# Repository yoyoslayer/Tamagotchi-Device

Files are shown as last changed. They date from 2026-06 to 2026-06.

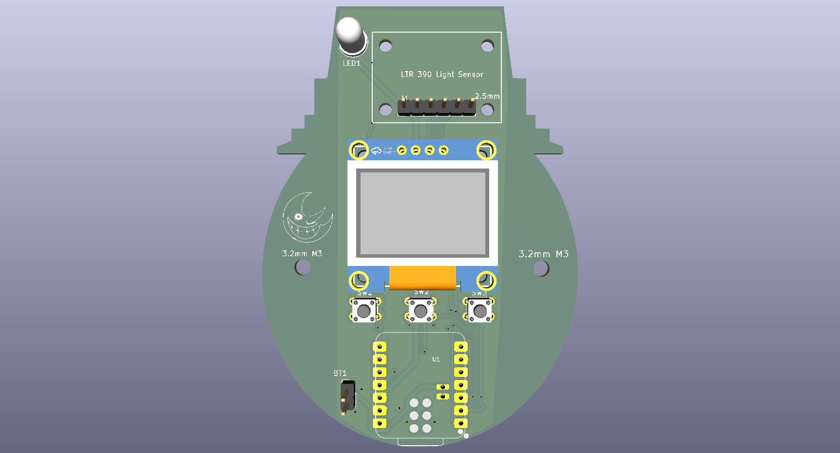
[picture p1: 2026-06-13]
Images/3D File Export Front.png

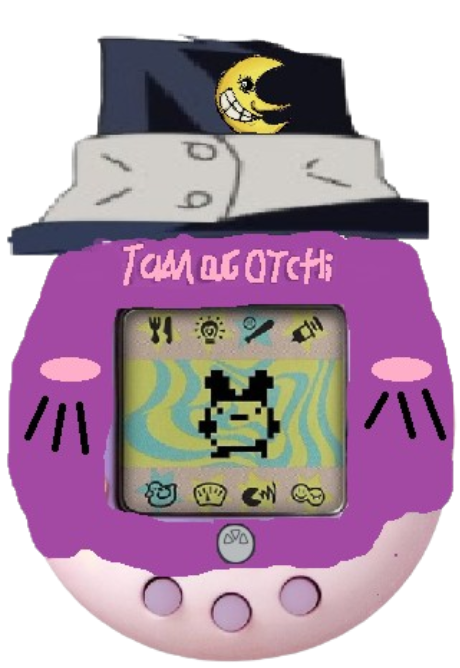
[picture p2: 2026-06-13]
Images/Rough Draft Case.png

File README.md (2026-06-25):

# Photophage. A pet that feeds on light

## What it is
I made a special digitel pet that you can carry around with you. It is like the Tamagotchi toys from the 90s but I built it myself and custom made. The pet is on a screen that comes with pressable buttons a buzzer, a LED, and a sensor that can tell if it is in the light or dark. All of this is inside an egg-shaped case that I made using a 3D printer. The case also takes inspiration and certain design elements from the AniManga, Soul Eater.
What makes my tamagotchi unique is that it can tell what is going on in your environment. It has a sensor that can tell if it present in sunlight, indoor lighting or if it is dark so it will react to where it is and not just to what you do with the buttons.

## What it does / how to use it
- There are three buttons that you can use to take care of the pet: Feed, Play, Sleep.
- The pet has three things that you need to keep track of: Hunger, Happiness, Energy. These will go down over time so you need to check on the pet
If you press Feed, the pets Hunger will go up.
If you press Play, the pets Happiness will go up. Its Energy will go down a little bit.
If you press Sleep the pets Energy will go up.

- The pets face will change depending on how it's feeling. It will be happy if it is doing well okay if it is getting by and sad if something is wrong.
- There is a light that will change color depending on how the pet is feeling: green means it is happy amber means it is okay and red means it needs help.
- When you press a button the pet will make a beep.
- The pet can tell if it is in sunlight or indoor light and it will show you this every minutes. If it is dark it will not say anything.
- The pet runs on a battery that you can recharge and it lives in a custom egg-shaped case that I made.

## Assembly
1. Download CAD files from onshape and the gerber zip.
2. Purchase the parts from the BOM or select alternatives. (Screws must be exact identicals in dimensions)
3. Order the PCB from JLCPCB (or your prefferred vendor) using the gerber file attached
4. Print the case enclosure that houses the PCB and components
5. Cut velcro tape to reasonable sizes and attach one half to the Battery enclosure in the bottom case and the other half to the battery.
6. Attach, assemble, and solder the parts to the PCB as it looks according to the Onshape CAD
   - Be sure to check your battery connection after soldering
   - Solder the battery cell into the bottom side of the PCB rather than the top
   - The JST PH connector's wire will need to be shortened significantly to fit in the bottom case or wrapped neatly. Solder the connector into the battery cell.
7. Insert heat inserts into their respective mounting holes, place PCB, then screw in the screws
8. Repeat step 6 for the case
9. Assembly complete. YAYYY

## Why I made it
I made Photophage because I wanted to try something challenging. This was my 1st time building a whole project from scratch and I wanted to add some special features like the light sensor and the mood light. I chose to make it a virtual pet that feeds on light because I think it is a fun and interesting idea. I used this project to learn about all the parts of building an electronics project from designing the circuit board to writing the code and making the case. This serves as my first submission to the program Fallout, created by HackClub, an organization that promotes and encourages teens to become engineers/programmers.


Tamagotchi Device 3D File Export Front
Tamagotchi Device 3D File Export Back


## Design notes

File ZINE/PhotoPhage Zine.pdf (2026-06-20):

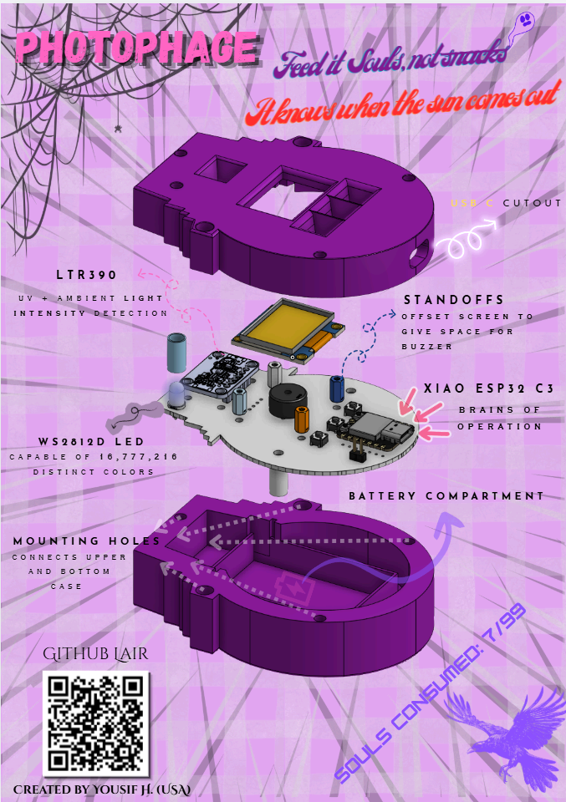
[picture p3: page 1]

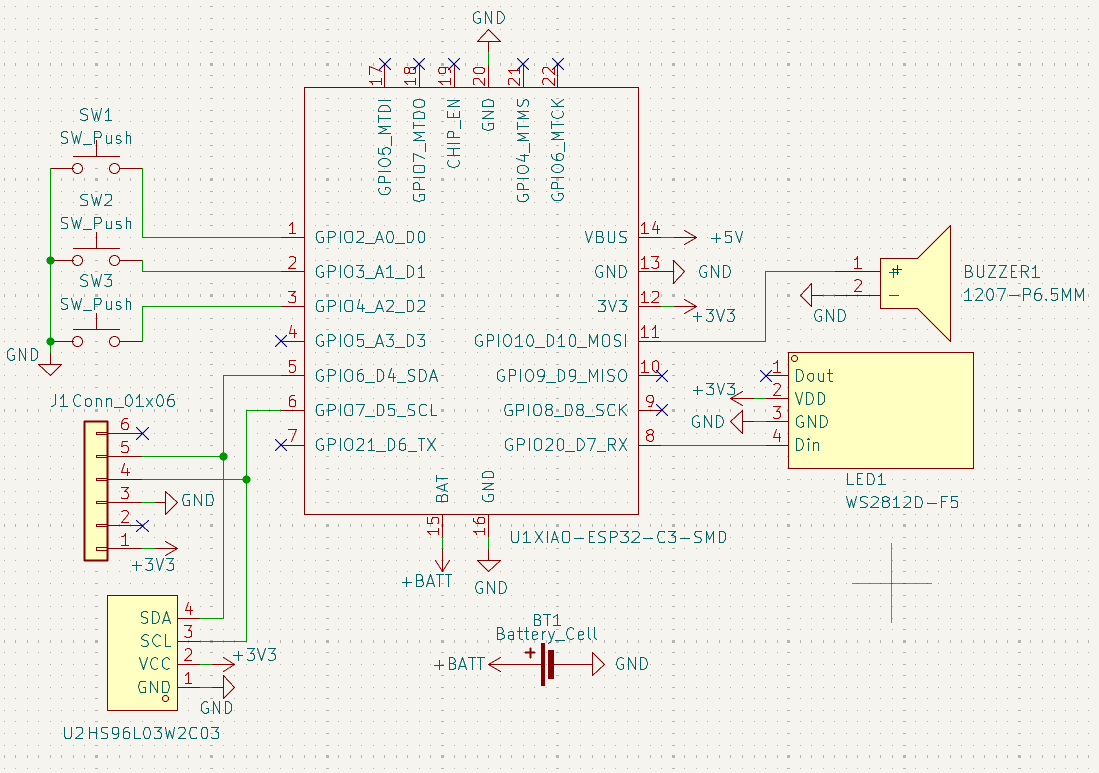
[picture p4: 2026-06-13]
Images/Schematic Image.png

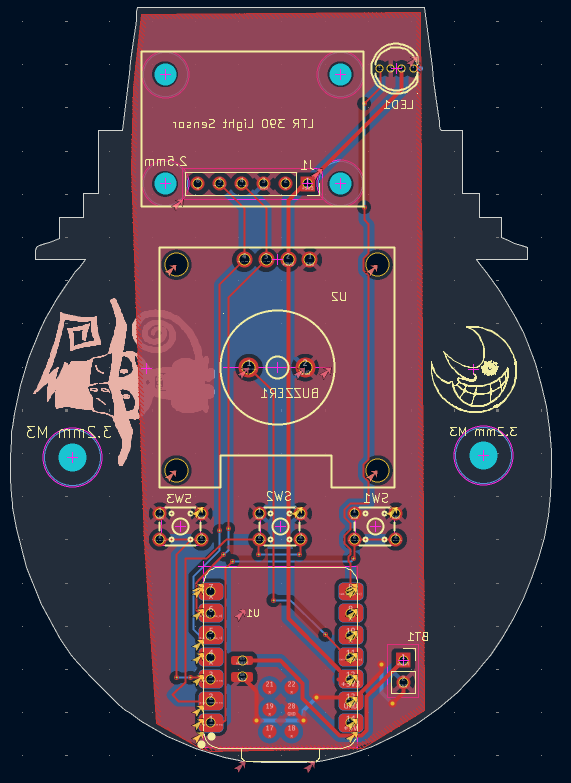
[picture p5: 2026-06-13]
Images/PCB View Bottom.png

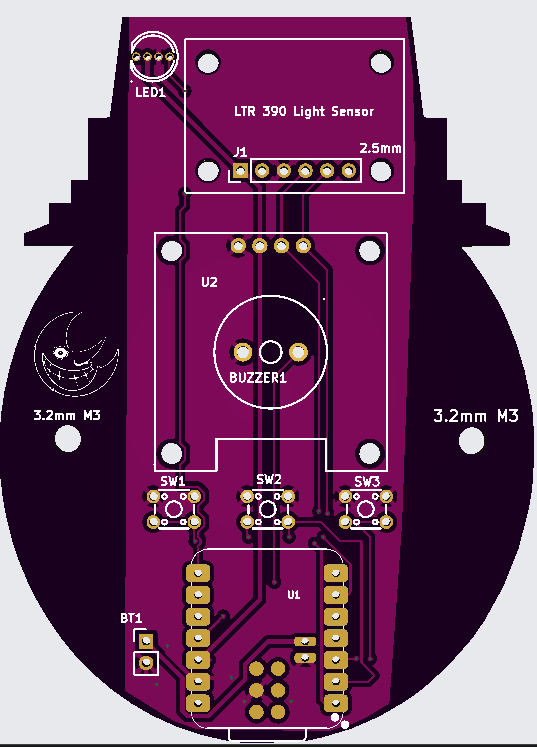
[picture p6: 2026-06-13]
Images/JLCPCB View PCB.png

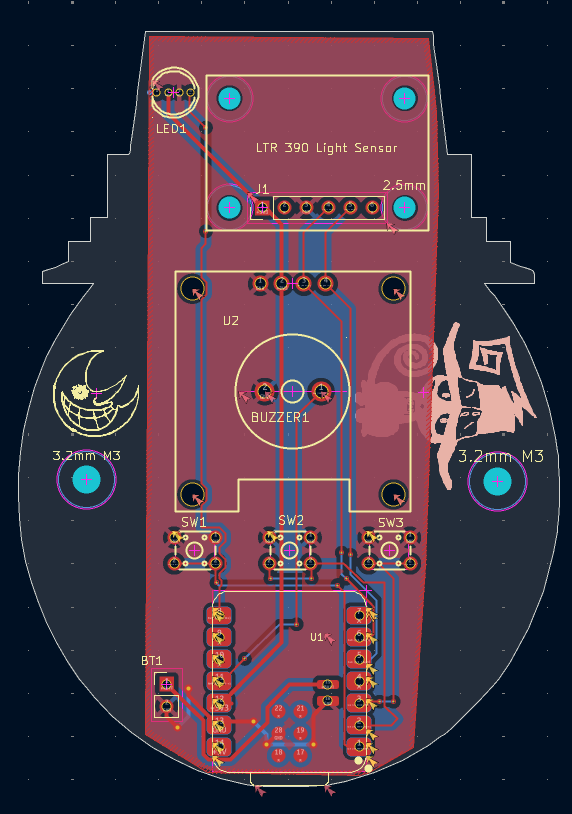
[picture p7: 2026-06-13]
Images/PCB View Top.png

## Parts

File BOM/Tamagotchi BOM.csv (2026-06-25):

Item | Description | Quantity | Individual piece quantity | Unit Price ($) | Total Price ($) | URL | Running Total ($ with Tax)
XIAO ESP32C3 | Microcontroller Unit | 1 | 1 | $4.99 | $4.99 | https://www.digikey.com/en/products/detail/seeed-technology-co-ltd/113991054/16652880 | $13.48
BRKWY 0.1" 36POS MALE 10PK | Breakaway Header Male Pin 2.54mm for Battery Cell | 1 | 10 | $4.95 | $4.95 | https://www.digikey.com/en/products/detail/adafruit-industries-llc/392/21283800 | $18.75
Worldsemi WS2812D-F5 | Multi Color LED | 1 | 5 | 0.2512 | $1.26 | https://www.lcsc.com/product-detail/C190565.html | 30
HS HS96L03W2C03 | OLED Screen | 1 | 1 | 2.244 | 2.244 | https://www.lcsc.com/product-detail/C5248080.html | 32.34
BZCN TSC016A04518A | Pressable Buttons | 1 | 50 | $0.01 | $0.54 | https://www.lcsc.com/product-detail/C2888493.html | 33.35
XHXDZ 1207-P6.5MM | Buzzer | 1 | 10 | $0.06 | $0.57 | https://www.lcsc.com/product-detail/C49246964.html | 34.07
Adafruit LTR390 | UV and Light Sensor | 1 | 1 | $4.95 | $4.95 | https://www.adafruit.com/product/4831 | 45.81
BATTERY LITH-ION 3.7V 1.2AH | Battery for powering Device | 1 | 1 | $3.00 | $3.00 | https://ydlbattery.com/products/100pcs-3-7v-1200mah-603450-lithium-polymer-battery | 63.54
20 SETS Mini Micro JST 2.0 PH 2-Pin Connector plug with Wires Cables 100MM | Connectors to wire the battery into the battery header pins | 1 | 20 | 2.68 | 2.68 | https://www.aliexpress.us/item/2251832479273592.html | 64.6
M3(OD4mm) 50Pcs Length 4mm | Heat Inserts to screw the nails into | 1 | 50 | $3.28 | $3.28 | https://www.aliexpress.us/item/3256810175696879.html | 67.7
M4(OD6mm) 30Pcs Length 4mm | Heat Inserts to screw the nails into | 1 | 30 | $3.37 | $3.37 | https://www.aliexpress.us/item/3256810175696879.html | 70.9
TPU 3D Printer Flexible Filament 250g (0.55lbs) 1.75mm Length 80M, Black, white | 3D Printer Filament | 1 | 1 | $21.78 | $21.78 | https://www.aliexpress.us/item/3256811629074080.html | 78.91
Self Adhesive Tape Hook and Loop Strips | Velcro to attach Battery to case | 1 | 5 | $3.28 | $3.28 | https://www.aliexpress.us/item/3256809228271173.html | 80.55
PCB from JLCPCB | The PCB that will be used for this project | 1 | 5 | $2.50 | $2.50 | https://jlcpcb.com/ | 85.85
Hakko CHP-170 | Micro Soft Wire Cutter | 1 | 1 | $5.20 | $5.20 | https://www.tequipment.net/Hakko/CHP-170/Cutting-Tools/ | 106.86
M4 x 0.7mm Zinc-Plated Socket Head Screw (5mm Length) | M4 Screws | 1 | 25 | $2.89 | $2.89 | https://www.gobilda.com/2800-series-zinc-plated-steel-socket-head-screw-m4-x-0-7mm-5mm-length-25-pack/ | 116.36
Zinc-Plated Steel Socket Head Screw (M3 x 0.5mm, 6mm Length) | M3 Screws | 1 | 6 | $2.99 | $2.99 | https://www.gobilda.com/zinc-plated-steel-socket-head-screw-m3-x-0-5mm-6mm-length-6-pack/ | 119.55
Note: Welcome Deal is applied to running total for Aliexpress items, my price will differ from yours if you do not have a welcome deal. There is no way to view my price without the welcome deal at checkout so keep that in mind

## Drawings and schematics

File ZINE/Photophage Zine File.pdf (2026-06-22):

# PPPhhhoootttoooppphhhaaagggeee

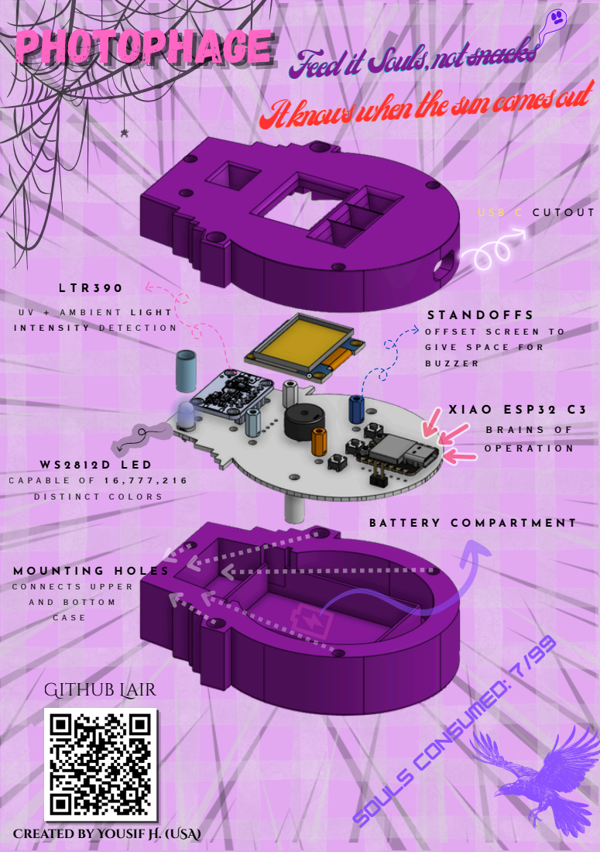
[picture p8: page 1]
Github Lair; Souls consumed: 7/99

Feedit Souls,notsnacks

Itknowswhenthesuncomesout Itknowswhenthesuncomesout Itknowswhenthesuncomesout

Created by Yousif H. (USA)

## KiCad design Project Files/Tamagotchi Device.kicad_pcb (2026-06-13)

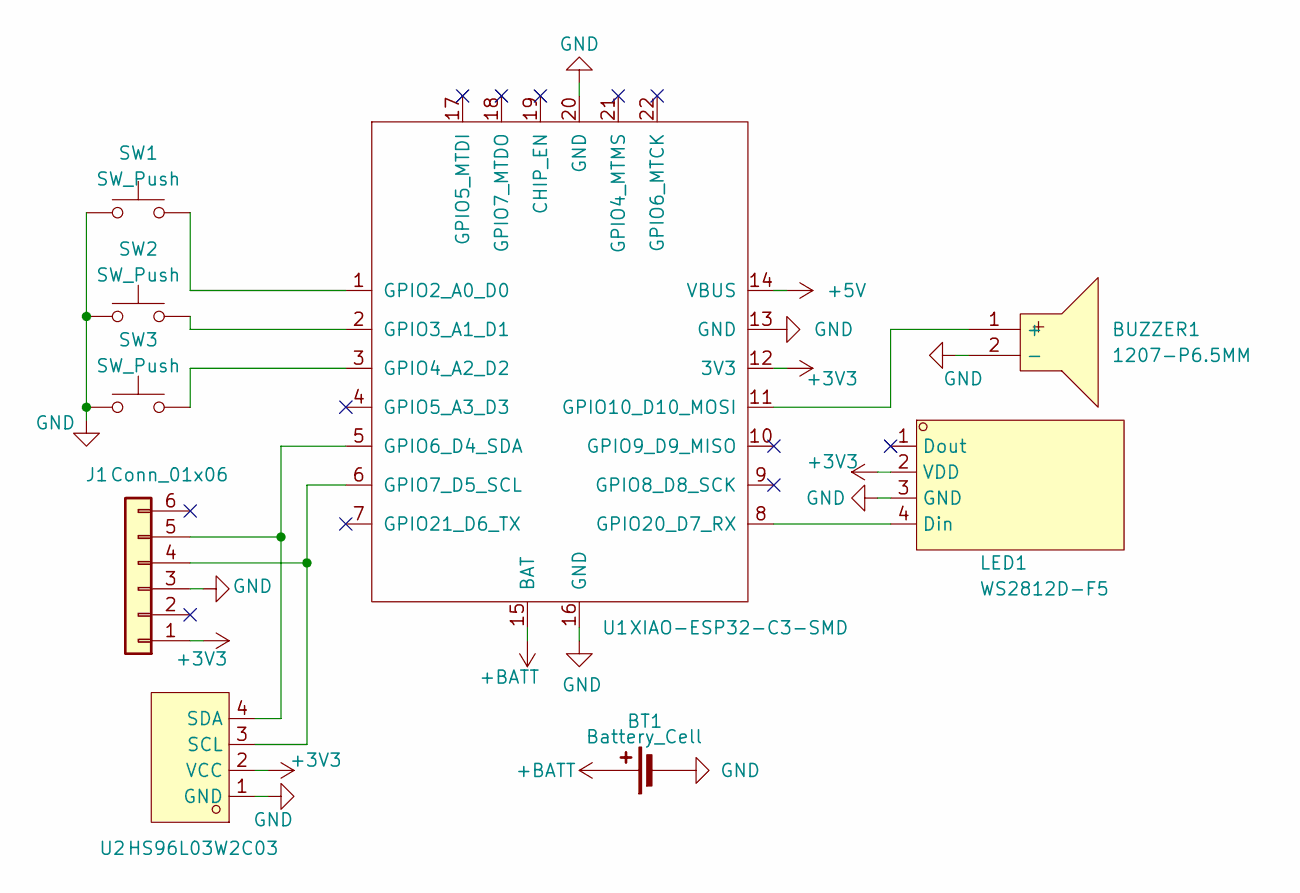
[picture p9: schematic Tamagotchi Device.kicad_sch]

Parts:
BT1: Battery_Cell; PinHeader_1x02_P2.54mm_Vertical
BUZZER1: 1207-P6.5MM; BUZ-TH_BD12.5-P6.50-D1.4; MPN 1207-P6.5MM; LCSC Part C49246964
J1: Conn_01x06; PinHeader_1x06_P2.54mm_Vertical
LED1: WS2812D-F5; LED-TH_4P-BD5.8-P1.30; MPN WS2812D-F5; LCSC Part C190565
SW1, SW2, SW3: SW_Push; SW-TH_4P-L4.5-W4.5-P3.00-LS4.8
U1: XIAO-ESP32-C3-SMD
U2: HS96L03W2C03; OLED-TH_L27.8-W27.2-P2.54_C9900033791; MPN HS96L03W2C03; LCSC Part C5248080

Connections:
+3V3: J1.1, LED1.2 (VDD), U1.12 (3V3), U2.2 (VCC)
+5V: U1.14 (VBUS)
+BATT: BT1.1 (+), U1.15 (BAT)
GND: BT1.2 (-), BUZZER1.2 (-), J1.3, LED1.3 (GND), SW1.1, SW2.1, SW3.1, U1.13 (GND), U1.16 (GND), U1.20 (GND), U2.1 (GND)
unnamed: BUZZER1.1 (+), U1.11 (GPIO10_D10_MOSI)
unnamed: J1.4, U1.6 (GPIO7_D5_SCL), U2.3 (SCL)
unnamed: J1.5, U1.5 (GPIO6_D4_SDA), U2.4 (SDA)
unnamed: LED1.4 (Din), U1.8 (GPIO20_D7_RX)
unnamed: SW1.2, U1.1 (GPIO2_A0_D0)
unnamed: SW2.2, U1.2 (GPIO3_A1_D1)
unnamed: SW3.2, U1.3 (GPIO4_A2_D2)

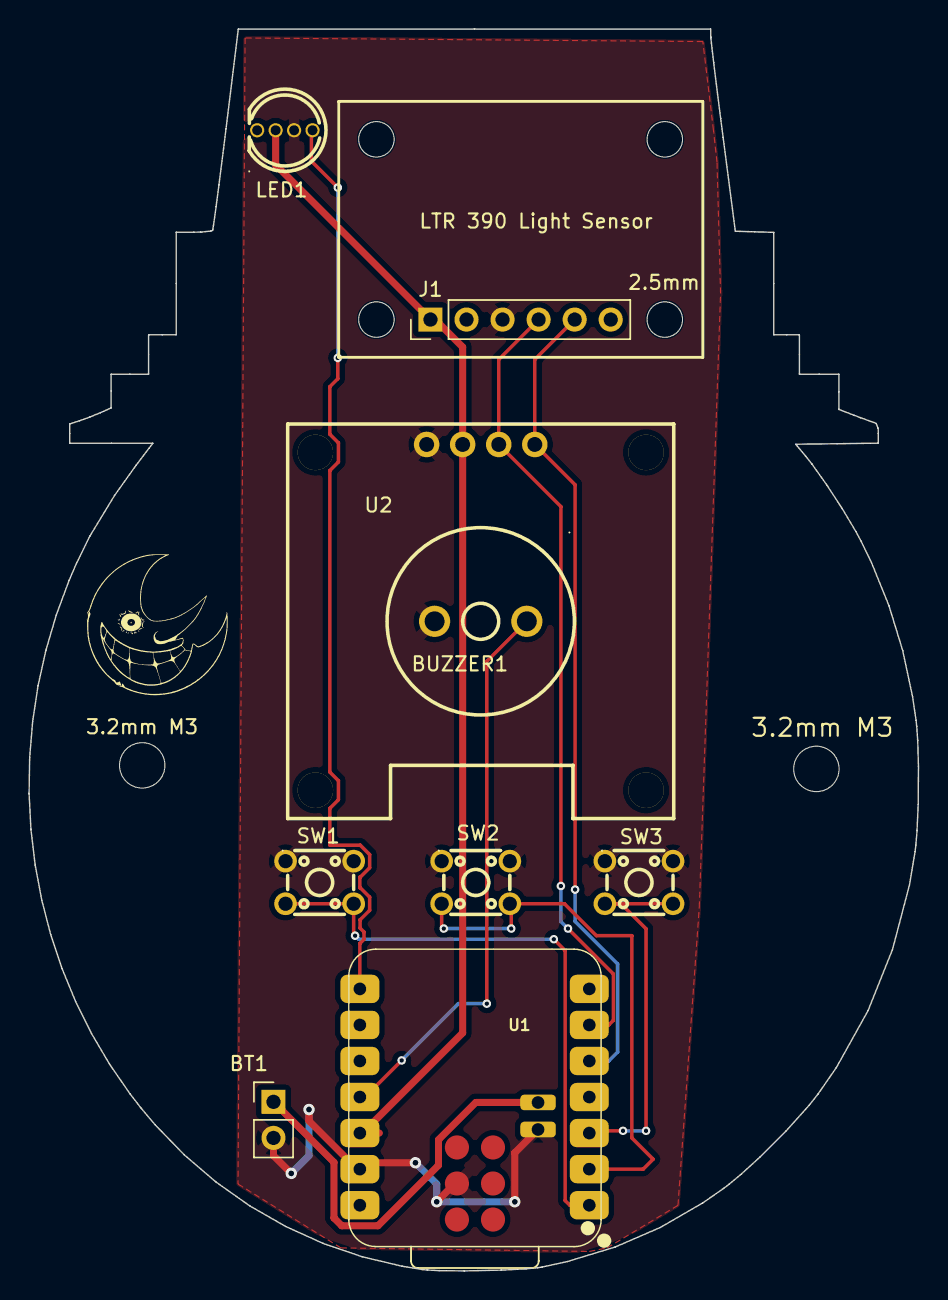
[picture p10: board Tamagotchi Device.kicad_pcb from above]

Board: 2 copper layers, 62.7 x 87.5 mm, 12 parts (0 on the bottom side), 10 nets.

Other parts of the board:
2.5mm, 2.5mm#2: MountingHole_2.5mm
3.2mm M3: MountingHole_3.2mm_M3

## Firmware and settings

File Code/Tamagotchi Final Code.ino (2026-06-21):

#include <Wire.h>
#include <Adafruit_GFX.h>
#include <Adafruit_SSD1306.h>
#include <Adafruit_NeoPixel.h>
#include <Adafruit_LTR390.h>

#define Screen_WIDTH 128
#define Screen_HEIGHT 64
#define OLED_RESET -1
Adafruit_SSD1306 display(Screen_WIDTH, Screen_HEIGHT, &Wire, OLED_RESET);

Adafruit_LTR390 ltr = Adafruit_LTR390();

#define BTN_LEFT   2
#define BTN_CENTER 3
#define BTN_RIGHT  4

#define SDA_PIN 6
#define SCL_PIN 7

#define BUZZER_PIN 10

#define LED_PIN 20

Adafruit_NeoPixel pixel(1, LED_PIN, NEO_GRB + NEO_KHZ800);

#define ALS_DARK_LEVEL 30
#define UV_SUN_LEVEL   50

#define ANNOUNCE_INTERVAL 300000UL
#define ANNOUNCE_DURATION 3000UL

struct Pet {
  int hunger;
  int happiness;
  int energy;
  unsigned long age;
};

Pet pet;

enum Screen {
  SCREEN_MAIN,
  SCREEN_FEED,
  SCREEN_PLAY,
  SCREEN_SLEEP,
};

Screen currentScreen = SCREEN_MAIN;

enum LightType {
  LIGHT_DARK,
  LIGHT_INDOOR,
  LIGHT_SUN,
};

LightType lightType = LIGHT_DARK;

void setup() {
  Serial.begin(115200);

  pinMode(BTN_LEFT, INPUT_PULLUP);
  pinMode(BTN_CENTER, INPUT_PULLUP);
  pinMode(BTN_RIGHT, INPUT_PULLUP);
  pinMode(BUZZER_PIN, OUTPUT);

  Wire.begin(SDA_PIN, SCL_PIN);

  display.begin(SSD1306_SWITCHCAPVCC, 0x3C);
  display.clearDisplay();
  display.setTextSize(1);
  display.setTextColor(SSD1306_WHITE);
  display.setCursor(0, 0);
  display.println("Tamagotchi Init...");
  display.display();

  if (!ltr.begin()) {
    Serial.println("LTR390 not found - check wiring/address");
  }
  ltr.setGain(LTR390_GAIN_3);
  ltr.setResolution(LTR390_RESOLUTION_16BIT);

  pixel.begin();
  pixel.setBrightness(50);
  pixel.clear();
  pixel.show();

  delay(1000);

  pet.hunger = 80;
  pet.happiness = 80;
  pet.energy = 80;
  pet.age = 0;
}

unsigned long lastUpdate = 0;

void updatePet() {
  if (millis() - lastUpdate > 5000) {
    pet.hunger--;
    pet.happiness--;
    pet.energy--;

    if (pet.hunger < 0) pet.hunger = 0;
    if (pet.happiness < 0) pet.happiness = 0;
    if (pet.energy < 0) pet.energy = 0;

    pet.age += 5;
    lastUpdate = millis();
  }
}

unsigned long lastButtonPress = 0;

void checkButtons() {
  if (millis() - lastButtonPress < 200) return;

  if (digitalRead(BTN_LEFT) == LOW) {
    currentScreen = SCREEN_FEED;
    tone(BUZZER_PIN, 1000, 50);
    lastButtonPress = millis();
  }
  else if (digitalRead(BTN_CENTER) == LOW) {
    currentScreen = SCREEN_PLAY;
    tone(BUZZER_PIN, 1000, 50);
    lastButtonPress = millis();
  }
  else if (digitalRead(BTN_RIGHT) == LOW) {
    currentScreen = SCREEN_SLEEP;
    tone(BUZZER_PIN, 1000, 50);
    lastButtonPress = millis();
  }
}

void handleScreenLogic() {
  switch (currentScreen) {
    case SCREEN_FEED:
      pet.hunger += 10;
      if (pet.hunger > 100) pet.hunger = 100;
      currentScreen = SCREEN_MAIN;
      break;

    case SCREEN_PLAY:
      pet.happiness += 10;
      pet.energy -= 5;
      if (pet.happiness > 100) pet.happiness = 100;
      if (pet.energy < 0) pet.energy = 0;
      currentScreen = SCREEN_MAIN;
      break;

    case SCREEN_SLEEP:
      pet.energy += 15;
      if (pet.energy > 100) pet.energy = 100;
      currentScreen = SCREEN_MAIN;
      break;

    case SCREEN_MAIN:
      break;
  }
}

unsigned long lastLightCheck = 0;

void checkLight() {
  if (millis() - lastLightCheck < 2000) return;
  lastLightCheck = millis();

  ltr.setMode(LTR390_MODE_ALS);
  delay(50);
  uint32_t visible = ltr.readALS();

  ltr.setMode(LTR390_MODE_UVS);
  delay(50);
  uint32_t uv = ltr.readUVS();

  if (visible < ALS_DARK_LEVEL) {
    lightType = LIGHT_DARK;
  } else if (uv > UV_SUN_LEVEL) {
    lightType = LIGHT_SUN;
  } else {
    lightType = LIGHT_INDOOR;
  }

  Serial.print("visible(ALS)="); Serial.print(visible);
  Serial.print("  uv(UVS)=");    Serial.print(uv);
  Serial.print("  -> ");
  Serial.println(lightType == LIGHT_SUN ? "SUN"
               : lightType == LIGHT_INDOOR ? "INDOOR" : "DARK");
}

unsigned long lastAnnounce = 0;
unsigned long announceUntil = 0;

void updateAnnounce() {
  if (millis() - lastAnnounce > ANNOUNCE_INTERVAL && lightType != LIGHT_DARK) {
    lastAnnounce = millis();
    announceUntil = millis() + ANNOUNCE_DURATION;
  }
}

bool isAnnouncing() {
  return millis() < announceUntil;
}

int petMood() {
  if (pet.hunger < 30 || pet.happiness < 30 || pet.energy < 30) return 0;
  if (pet.hunger > 50 && pet.happiness > 50 && pet.energy > 50) return 2;
  return 1;
}

void updateLED() {
  uint32_t color;
  switch (petMood()) {
    case 0:  color = pixel.Color(255, 0, 0);   break;
    case 2:  color = pixel.Color(0, 255, 0);   break;
    default: color = pixel.Color(255, 170, 0);
  }
  pixel.setPixelColor(0, color);
  pixel.show();
}

const unsigned char PROGMEM petHappy[] = {
  0b00000000, 0b00000000,
  0b00001111, 0b11110000,
  0b00011000, 0b00011000,
  0b00110000, 0b00001100,
  0b01100000, 0b00000110,
  0b01001110, 0b01110010,
  0b01000000, 0b00000010,
  0b01000000, 0b00000010,
  0b01011000, 0b00011010,
  0b01011000, 0b00011010,
  0b01001100, 0b00110010,
  0b01100111, 0b11100110,
  0b00010000, 0b00001000,
  0b00001100, 0b00110000,
  0b00000111, 0b11100000,
  0b00000000, 0b00000000
};

const unsigned char PROGMEM petSad[] = {
  0b00000000, 0b00000000,
  0b00001111, 0b11110000,
  0b00011000, 0b00011000,
  0b00110000, 0b00001100,
  0b01100000, 0b00000110,
  0b01001110, 0b01110010,
  0b01000000, 0b00000010,
  0b01000000, 0b00000010,
  0b01000011, 0b11000010,
  0b01000110, 0b01100010,
  0b01001100, 0b00110010,
  0b01100000, 0b00000110,
  0b00010000, 0b00001000,
  0b00001100, 0b00110000,
  0b00000111, 0b11100000,
  0b00000000, 0b00000000
};

const unsigned char PROGMEM petNeutral[] = {
  0b00000000, 0b00000000,
  0b00001111, 0b11110000,
  0b00011000, 0b00011000,
  0b00110000, 0b00001100,
  0b01100000, 0b00000110,
  0b01001110, 0b01110010,
  0b01000000, 0b00000010,
  0b01000000, 0b00000010,
  0b01000000, 0b00000010,
  0b01000000, 0b00000010,
  0b01001111, 0b11110010,
  0b01100000, 0b00000110,
  0b00010000, 0b00001000,
  0b00001100, 0b00110000,
  0b00000111, 0b11100000,
  0b00000000, 0b00000000
};

const unsigned char PROGMEM petSleepy[] = {
  0b00000000, 0b00000000,
  0b00001111, 0b11110000,
  0b00011000, 0b00011000,
  0b00110000, 0b00001100,
  0b01101010, 0b01010110,
  0b01000100, 0b00100010,
  0b01001010, 0b01010010,
  0b01000000, 0b00000010,
  0b01000000, 0b00000010,
  0b01000000, 0b00000010,
  0b01000011, 0b11000010,
  0b01100000, 0b00000110,
  0b00010000, 0b00001000,
  0b00001100, 0b00110000,
  0b00000111, 0b11100000,
  0b00000000, 0b00000000
};

const unsigned char PROGMEM petSunshine[] = {
  0b00000000, 0b00000000,
  0b00011111, 0b11111000,
  0b00111000, 0b00011100,
  0b01110000, 0b00001110,
  0b01101010, 0b01010110,
  0b01001010, 0b01010010,
  0b01001110, 0b01110010,
  0b01000000, 0b00000010,
  0b01001000, 0b00010010,
  0b01001000, 0b00010010,
  0b01001100, 0b00110010,
  0b01100111, 0b11100110,
  0b00010000, 0b00001000,
  0b00001100, 0b00110000,
  0b00000111, 0b11100000,
  0b00000000, 0b00000000
};

const unsigned char PROGMEM petIndoor[] = {
  0b00000000, 0b00000000,
  0b00011111, 0b11111000,
  0b00111000, 0b00011100,
  0b01110000, 0b00001110,
  0b01101110, 0b01110110,
  0b01001010, 0b01010010,
  0b01001110, 0b01110010,
  0b01000000, 0b00000010,
  0b01000000, 0b00000010,
  0b01001000, 0b00010010,
  0b01001100, 0b00110010,
  0b01100111, 0b11100110,
  0b00010000, 0b00001000,
  0b00001100, 0b00110000,
  0b00000111, 0b11100000,
  0b00000000, 0b00000000
};

void drawBar(int x, int y, int value) {
  int barWidth = 100;
  int barHeight = 6;
  int fillWidth = map(value, 0, 100, 0, barWidth);
  display.drawRect(x, y, barWidth, barHeight, SSD1306_WHITE);
  display.fillRect(x, y, fillWidth, barHeight, SSD1306_WHITE);
}

void render() {
  display.clearDisplay();

  const unsigned char* sprite;
  if (isAnnouncing()) {
    if (lightType == LIGHT_SUN) {
      sprite = petSunshine;
      display.setCursor(0, 4);
      display.print("Sun!");
    } else {
      sprite = petIndoor;
      display.setCursor(0, 4);
      display.print("Indoor");
    }
  } else {
    switch (petMood()) {
      case 0:  sprite = petSad;     break;
      case 2:  sprite = petHappy;   break;
      default: sprite = petNeutral;
    }
  }

  display.drawBitmap(56, 2, sprite, 16, 16, SSD1306_WHITE);

  display.setTextSize(1);
  display.setCursor(0, 24);
  display.print("HUN ");
  drawBar(24, 24, pet.hunger);
  display.setCursor(0, 34);
  display.print("HAP ");
  drawBar(24, 34, pet.happiness);
  display.setCursor(0, 44);
  display.print("ENG ");
  drawBar(24, 44, pet.energy);

  display.setCursor(0, 56);
  display.println("[Feed] [Play] [Sleep]");

  display.display();
}

void loop() {
  checkButtons();
  updatePet();
  handleScreenLogic();
  checkLight();
  updateAnnounce();
  updateLED();
  render();
  delay(100);
}

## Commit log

2026-06-13 Add link to Bill of Materials spreadsheet
2026-06-21 Reorganizing files
    [Tamagotchi BOM - Sheet1.csv, Tamagotchi Device.kicad_pcb, Tamagotchi Device.kicad_sch]
2026-06-25 Revise assembly steps in README for clarity
    Updated assembly instructions for battery attachment and soldering.
